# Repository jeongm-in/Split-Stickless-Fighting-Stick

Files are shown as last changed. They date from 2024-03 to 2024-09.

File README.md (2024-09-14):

# Split Stickless Fighting Game Controller - Version 1
- Most commercial fighting game controllers all have very "crowded" layout. I wanted to make something that gives ample space between my left and right hands, and also learn how to design PCB from scratch. 

# Design 
- Split between left (Movement) and right (Other controls)
- Followed [ai03's PCB Design](https://wiki.ai03.com/books/pcb-design) guide for the KiCad part
- Uses RJ45 (Commonly used in Ethernet cables) to connect both sides 
    - TRRS Cables (Commonly used in headphone jacks with microphone) are usually used in split keyboards, but this only supports up to 4 connections.
    - I needed minimum 5 pins (UP, LEFT, RIGHT, DOWN, and GND) on the Left, so I had to use something with more connections. 
    - May explore with different connector in future revisions (USB Type C?)
- Uses GP2040-CE and has all the button mappings of a PS4 controller. So this could maybe "tournament legal", though I don't intend to use this in contests
- Also hotswappable! Bring any keyboard switch you want 

# Pin layout 

| GPIO Pin | Button | GPIO Pin  | Button |
| --- | --- | --- | --- |
| 00 | A1 (Capture) | 15 | L3 (LS) |
| 01 | Down | 16 | R3 (RS) | 
| 02 | A2 (Home) | 17 | R2 (RT) | 
| 03 | Up | 18 | L2 (LT) | 
| 04 | Right | 19 | B2 | 
| 05 | Left | 20 | B1 | 
| 06 | None | 21 | None | 
| 07 | None | 22 | R1 (RB) | 
| 08 | S2 (Share) | 23 | None | 
| 09 | None | 24 | None | 
| 10 | None | 25 | None | 
| 11 | None | 26 | L1 (LB) | 
| 12 | None | 27 | B4 | 
| 13 | S1 (Option) | 28 | B3 | 
| 14 | None | 29 | None |

* See [Documentation](https://gp2040-ce.info/usage) for button mappings

* Also see [Config](https://github.com/jeongm-in/Split-Stickless-Fighting-Stick/blob/main/Config/gp2040ce_backup_20240914181731127.gp2040) directory to download the config file that can be loaded in GP2040-CE

# Parts 
- 1 Raspberry Pi Pico
- 2 Amphenol RJHSE-5380 (8P8C RJ45 female adapter)
- 4 Omron B3F-1020 switches (or any B3F-10x)
- 12 Cherry MX compatible switches of your choice 
- 12 Kailh Hotswap sockets
- 12 Keycaps of your choice

# PCB Design
Front
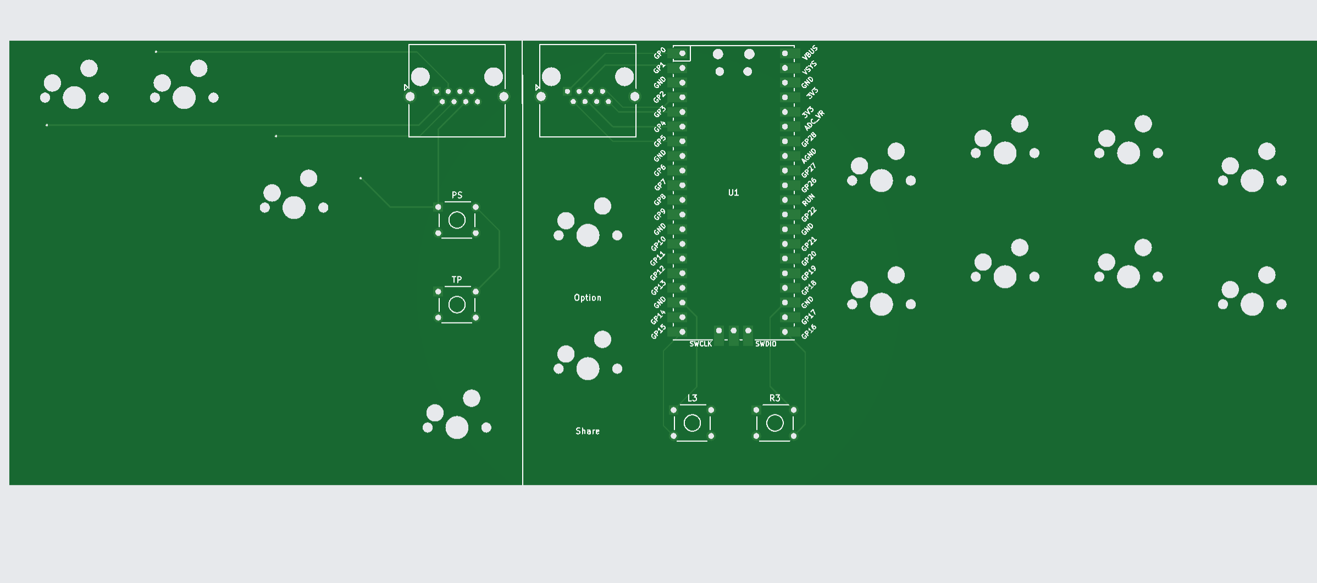
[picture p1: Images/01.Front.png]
front

Back
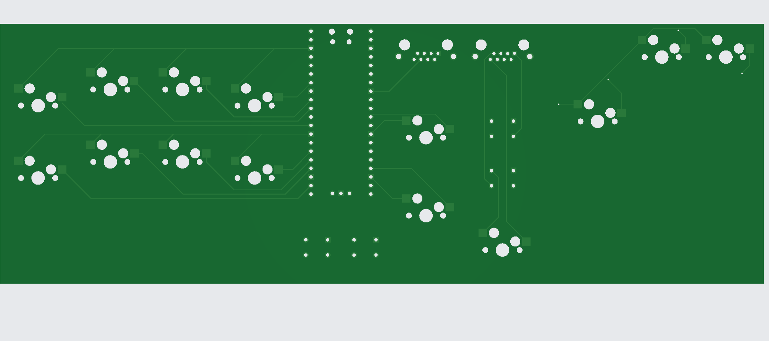
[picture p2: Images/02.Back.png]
back


# Assembly 
Finally got all the parts in mail and assembled the board. V-Cut groove was very easy to split.

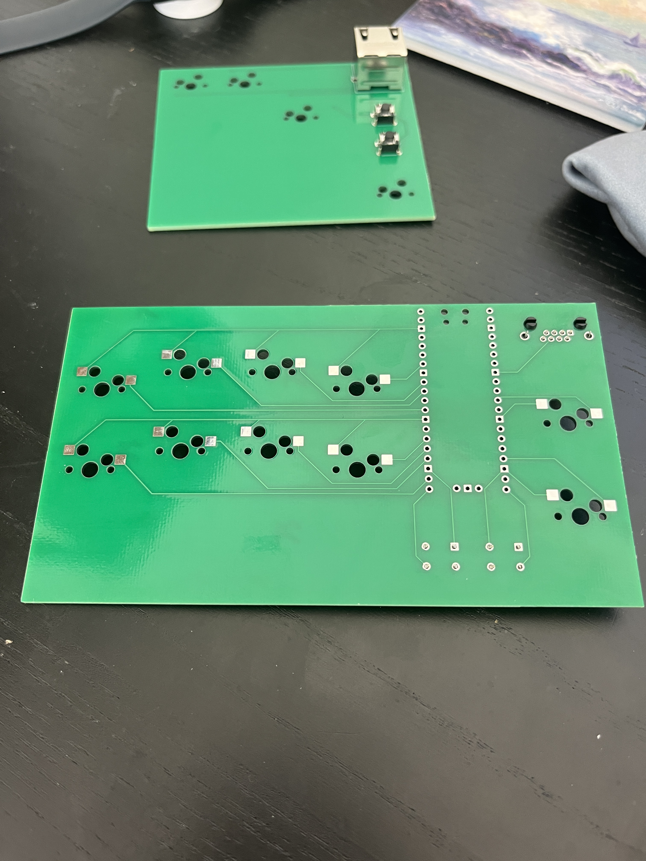
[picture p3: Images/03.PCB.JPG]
PCB


And then soldered the components onto the board. Pi Pico I got was very hard to solder properly, but I managed to get everything done without shorting anything. 

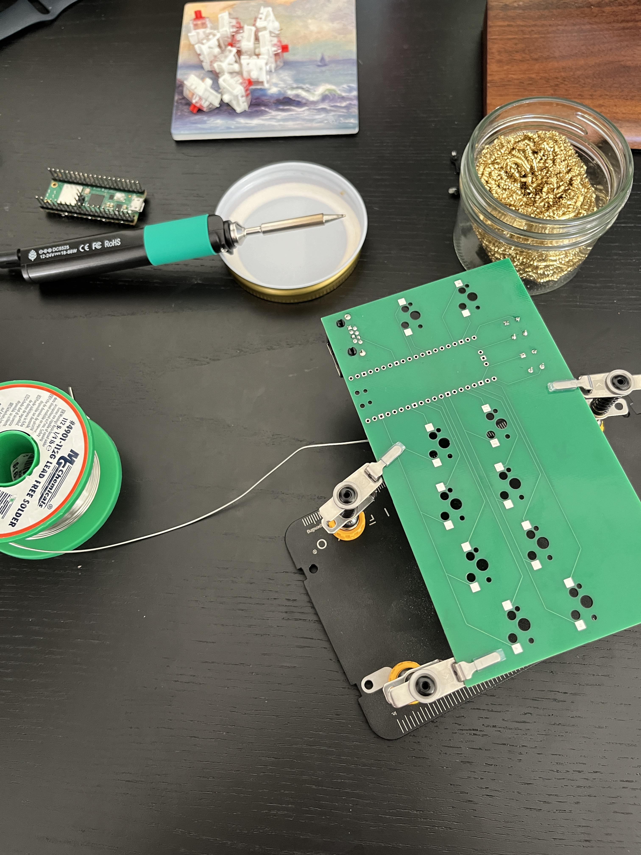
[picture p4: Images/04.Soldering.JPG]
Soldering


After the assembly, I installed GP2040-CE firmware and tested every button is working as expected. Since I changed the pins for easy routing, my layout is different from the out of the box default. 

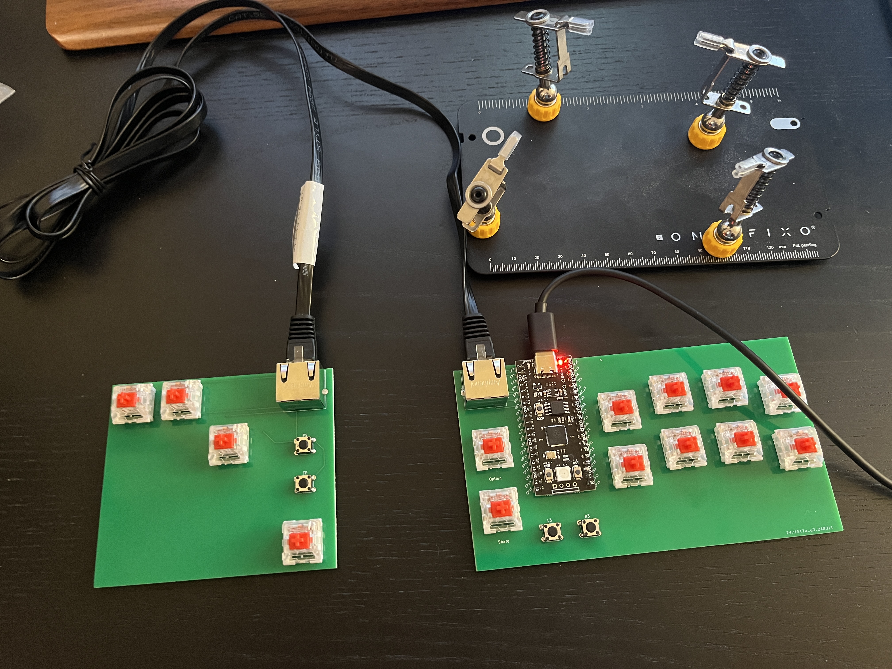
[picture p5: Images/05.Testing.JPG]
Test


Luckily I somehow soldered everything fine and it worked perfectly. Put on some keycaps from my "Mechanical Keyboard days" for fun.

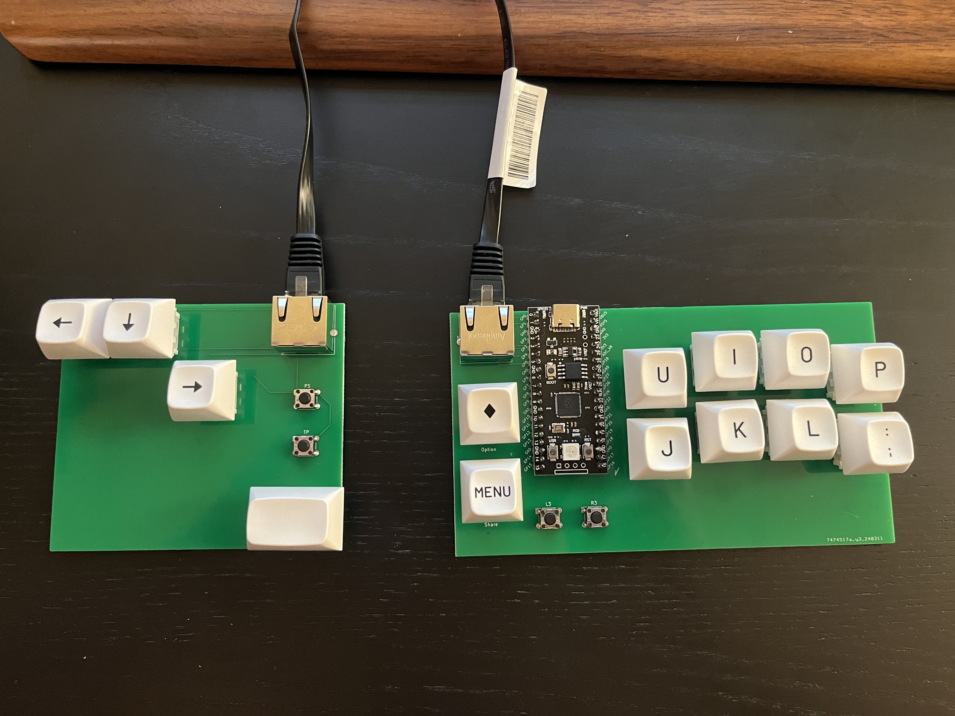
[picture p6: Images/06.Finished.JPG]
Finished


It is a little awkward so I'll need some time to get used to it, but I'm glad it all works correctly. Hotswap sockets are surprisingly sturdy and I don't think I would even need a face plate to hold the switches in place. I would still need some spacers with rubber feet to prevent boards from moving around, but it is ready for use now. 

Overall this was a very fun project, I'm glad I actually finished a project this time. I still have 4 more PCBs so I may assemble remainder when I get bored. Might also come back with V2 sometime in the future with more improvements. 

# ToDo 
- Exterior case / plate / feet for the board
- Rename KiCad project name from my-split to something meaningful

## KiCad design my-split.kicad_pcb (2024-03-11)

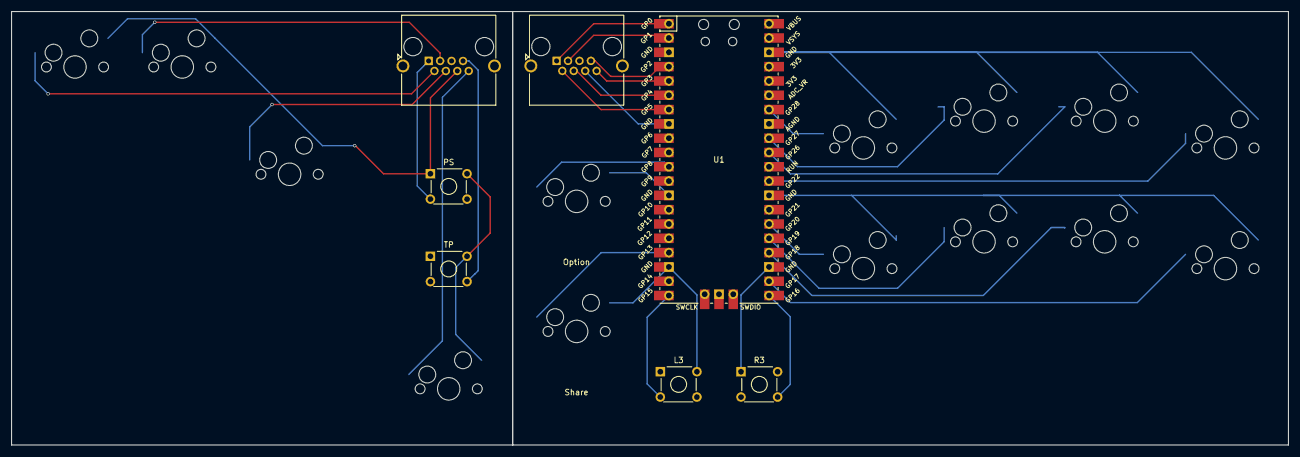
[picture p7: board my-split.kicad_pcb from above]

Board: 2 copper layers, 226.7 x 77.0 mm, 21 parts (0 on the bottom side), 26 nets.

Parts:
J1, J3: 8P8C; RJ45_Amphenol_RJHSE5380
L3: SW_Omron_B3FS; SW_TH_Tactile_Omron_B3F-10xx
MX1, MX2, MX3, MX4, MX5, MX9, MX10, MX13, MX14, MX15, MX16, MX17, MX18, MX19: MX-NoLED; MXOnly-1U-Hotswap
PS: SW_Omron_B3FS; SW_TH_Tactile_Omron_B3F-10xx
R3: SW_Omron_B3FS; SW_TH_Tactile_Omron_B3F-10xx
TP: SW_Omron_B3FS; SW_TH_Tactile_Omron_B3F-10xx
U1: Pico; RPi_Pico_SMD_TH

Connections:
A1 - Home: J1.1, U1.1 (GPIO0)
A1 - Home - LEFT: J3.1, PS.2
A2 - Capture: J1.7, U1.4 (GPIO2)
A2 - Capture - LEFT: J3.7, TP.2
B1 - A: MX15.1 (COL), U1.26 (GPIO20)
B2 - B: MX16.1 (COL), U1.25 (GPIO19)
B3 - X: MX9.1 (COL), U1.34 (GPIO28_ADC2)
B4 - Y: MX10.1 (COL), U1.32 (GPIO27_ADC1)
DOWN: J1.3, U1.2 (GPIO1)
DOWN - LEFT: J3.3, MX3.1 (COL)
GND: J1.6, L3.1, MX1.2 (ROW), MX5.2 (ROW), MX9.2 (ROW), MX10.2 (ROW), MX13.2 (ROW), MX14.2 (ROW), MX15.2 (ROW), MX16.2 (ROW), MX17.2 (ROW), MX18.2 (ROW), R3.1, U1.3 (GND), U1.8 (GND), U1.13 (GND), U1.18 (GND), U1.23 (GND), U1.28 (GND), U1.38 (GND)
GND - LEFT: J3.6, MX2.2 (ROW), MX3.2 (ROW), MX4.2 (ROW), MX19.2 (ROW), PS.1, TP.1
L1 - LB: MX13.1 (COL), U1.31 (GPIO26_ADC0)
L2 - LT: MX17.1 (COL), U1.24 (GPIO18)
L3 - LS: L3.2, U1.20 (GPIO15)
LEFT: J1.2, U1.7 (GPIO5)
LEFT - LEFT: J3.2, MX2.1 (COL)
R1 - RB: MX14.1 (COL), U1.29 (GPIO22)
R2 - RT: MX18.1 (COL), U1.22 (GPIO17)
R3 - RS: R3.2, U1.21 (GPIO16)
RIGHT: J1.4, U1.6 (GPIO4)
RIGHT - LEFT: J3.4, MX4.1 (COL)
S1 - Share: MX5.1 (COL), U1.17 (GPIO13)
S2 - Options: MX1.1 (COL), U1.11 (GPIO8)
UP: J1.8, U1.5 (GPIO3)
UP - LEFT: J3.8, MX19.1 (COL)

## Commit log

2024-03-10 Publish project on GitHub
    [my-split-B_Cu.gbl, my-split-B_Paste.gbp, my-split-B_Silkscreen.gbo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]
2024-03-10 Apply .gitignore changes
    [pcb-v0.step]
2024-03-11 Update design per review from the PCB manufacturer
    [my-split-B_Cu.gbl, my-split-B_Mask.gbs, my-split-Edge_Cuts.gm1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]
